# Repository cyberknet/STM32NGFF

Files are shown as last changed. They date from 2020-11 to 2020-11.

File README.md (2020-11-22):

# STM32NGFF
# About
STM32 breakout board using NGFF card edge connector

For licensing information please see our LICENSE file

Created by the members of 33C (fka reindeer pig baboon with mouse accessory)

## Schematic
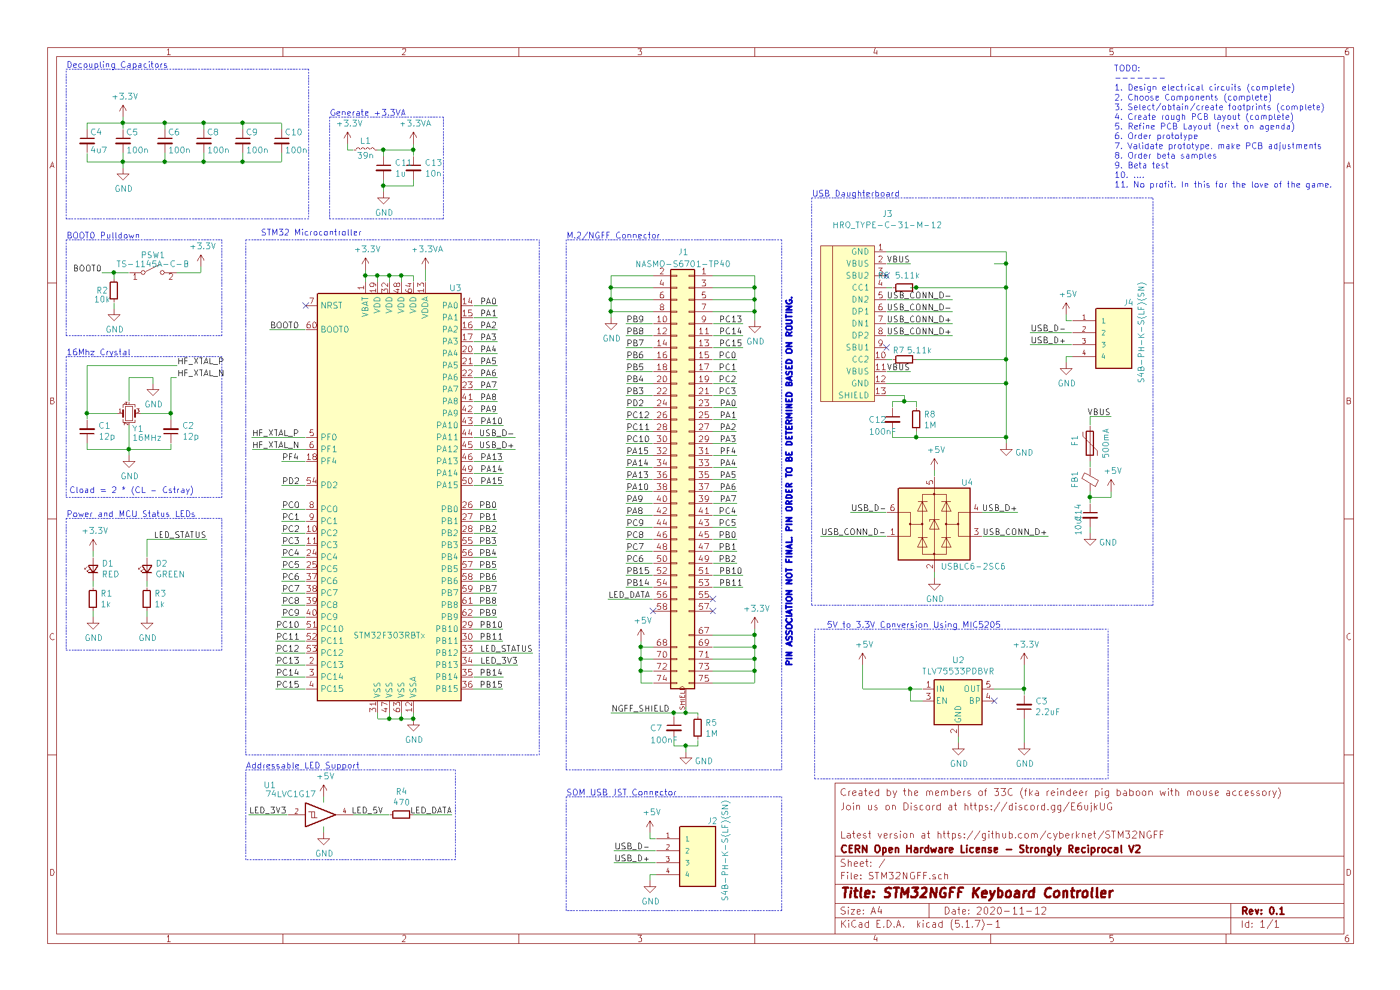
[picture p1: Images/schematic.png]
Keyboard Schematic


## PCB
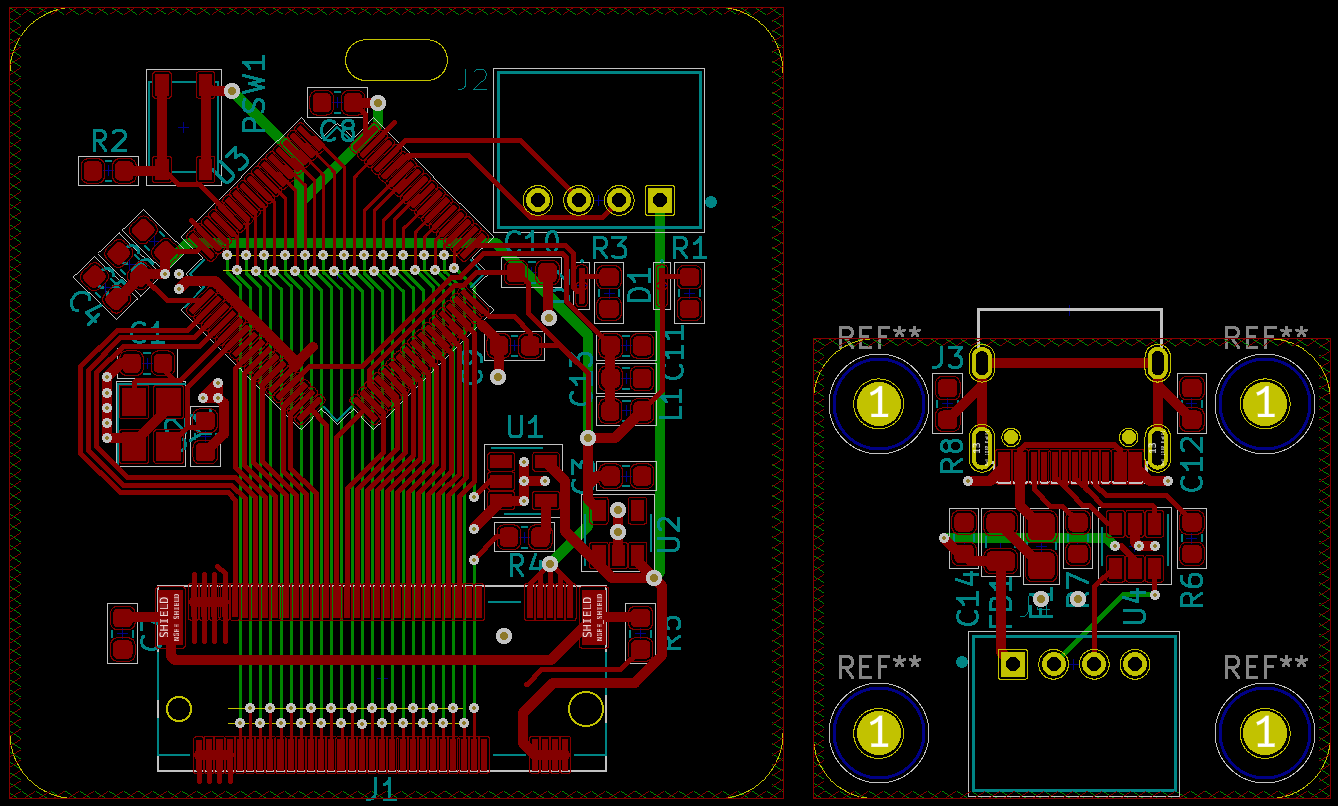
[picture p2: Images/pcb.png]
PCB


## PCB 3D View
Front:
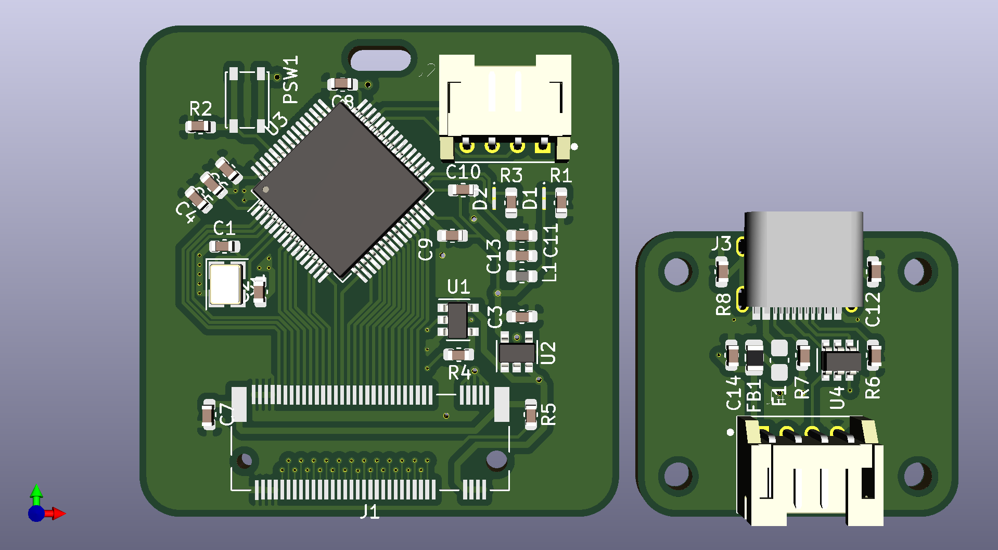
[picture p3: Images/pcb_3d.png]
PCB 3D Front View

Back:
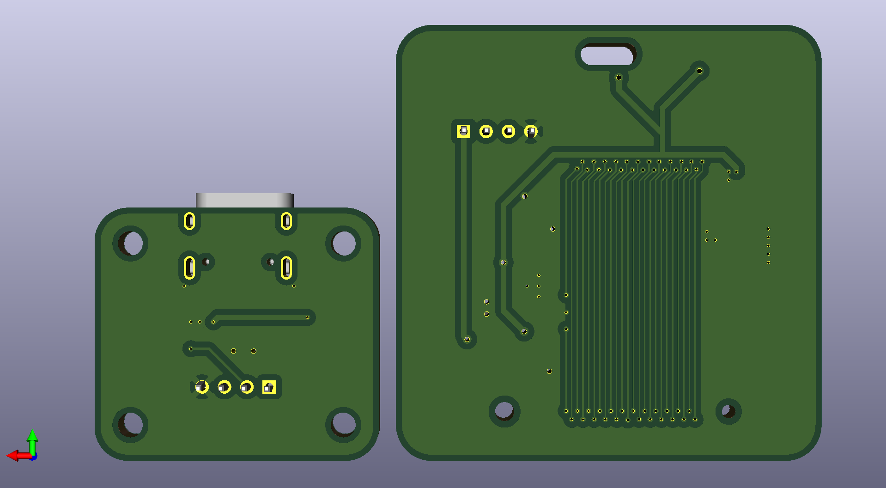
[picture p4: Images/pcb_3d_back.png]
PCB 3D Back View

Traces
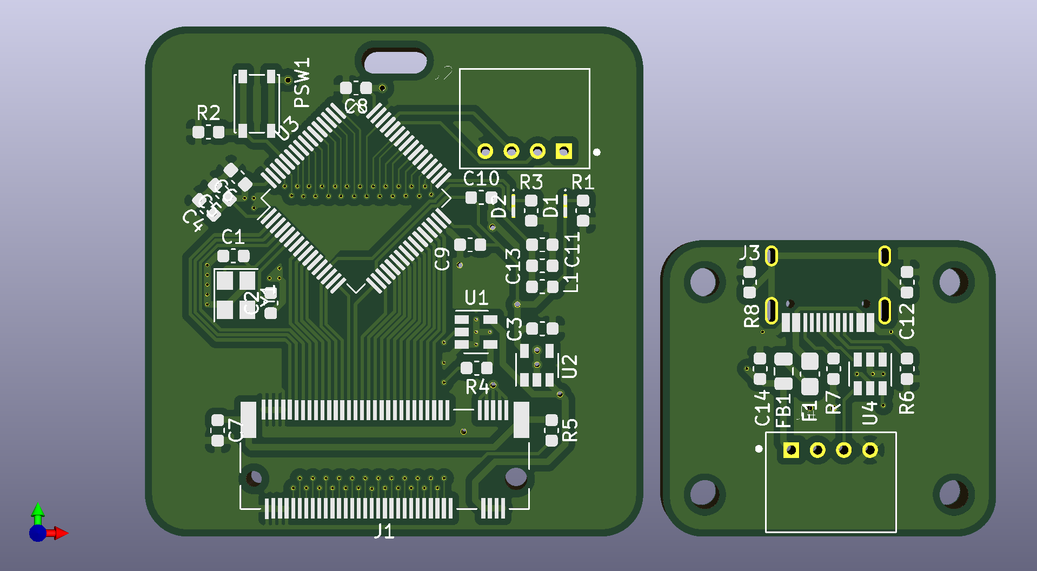
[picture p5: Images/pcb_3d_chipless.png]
PCB 3D Front Trace View


# Contact
Join us on Discord at https://discord.gg/E6ujkUG

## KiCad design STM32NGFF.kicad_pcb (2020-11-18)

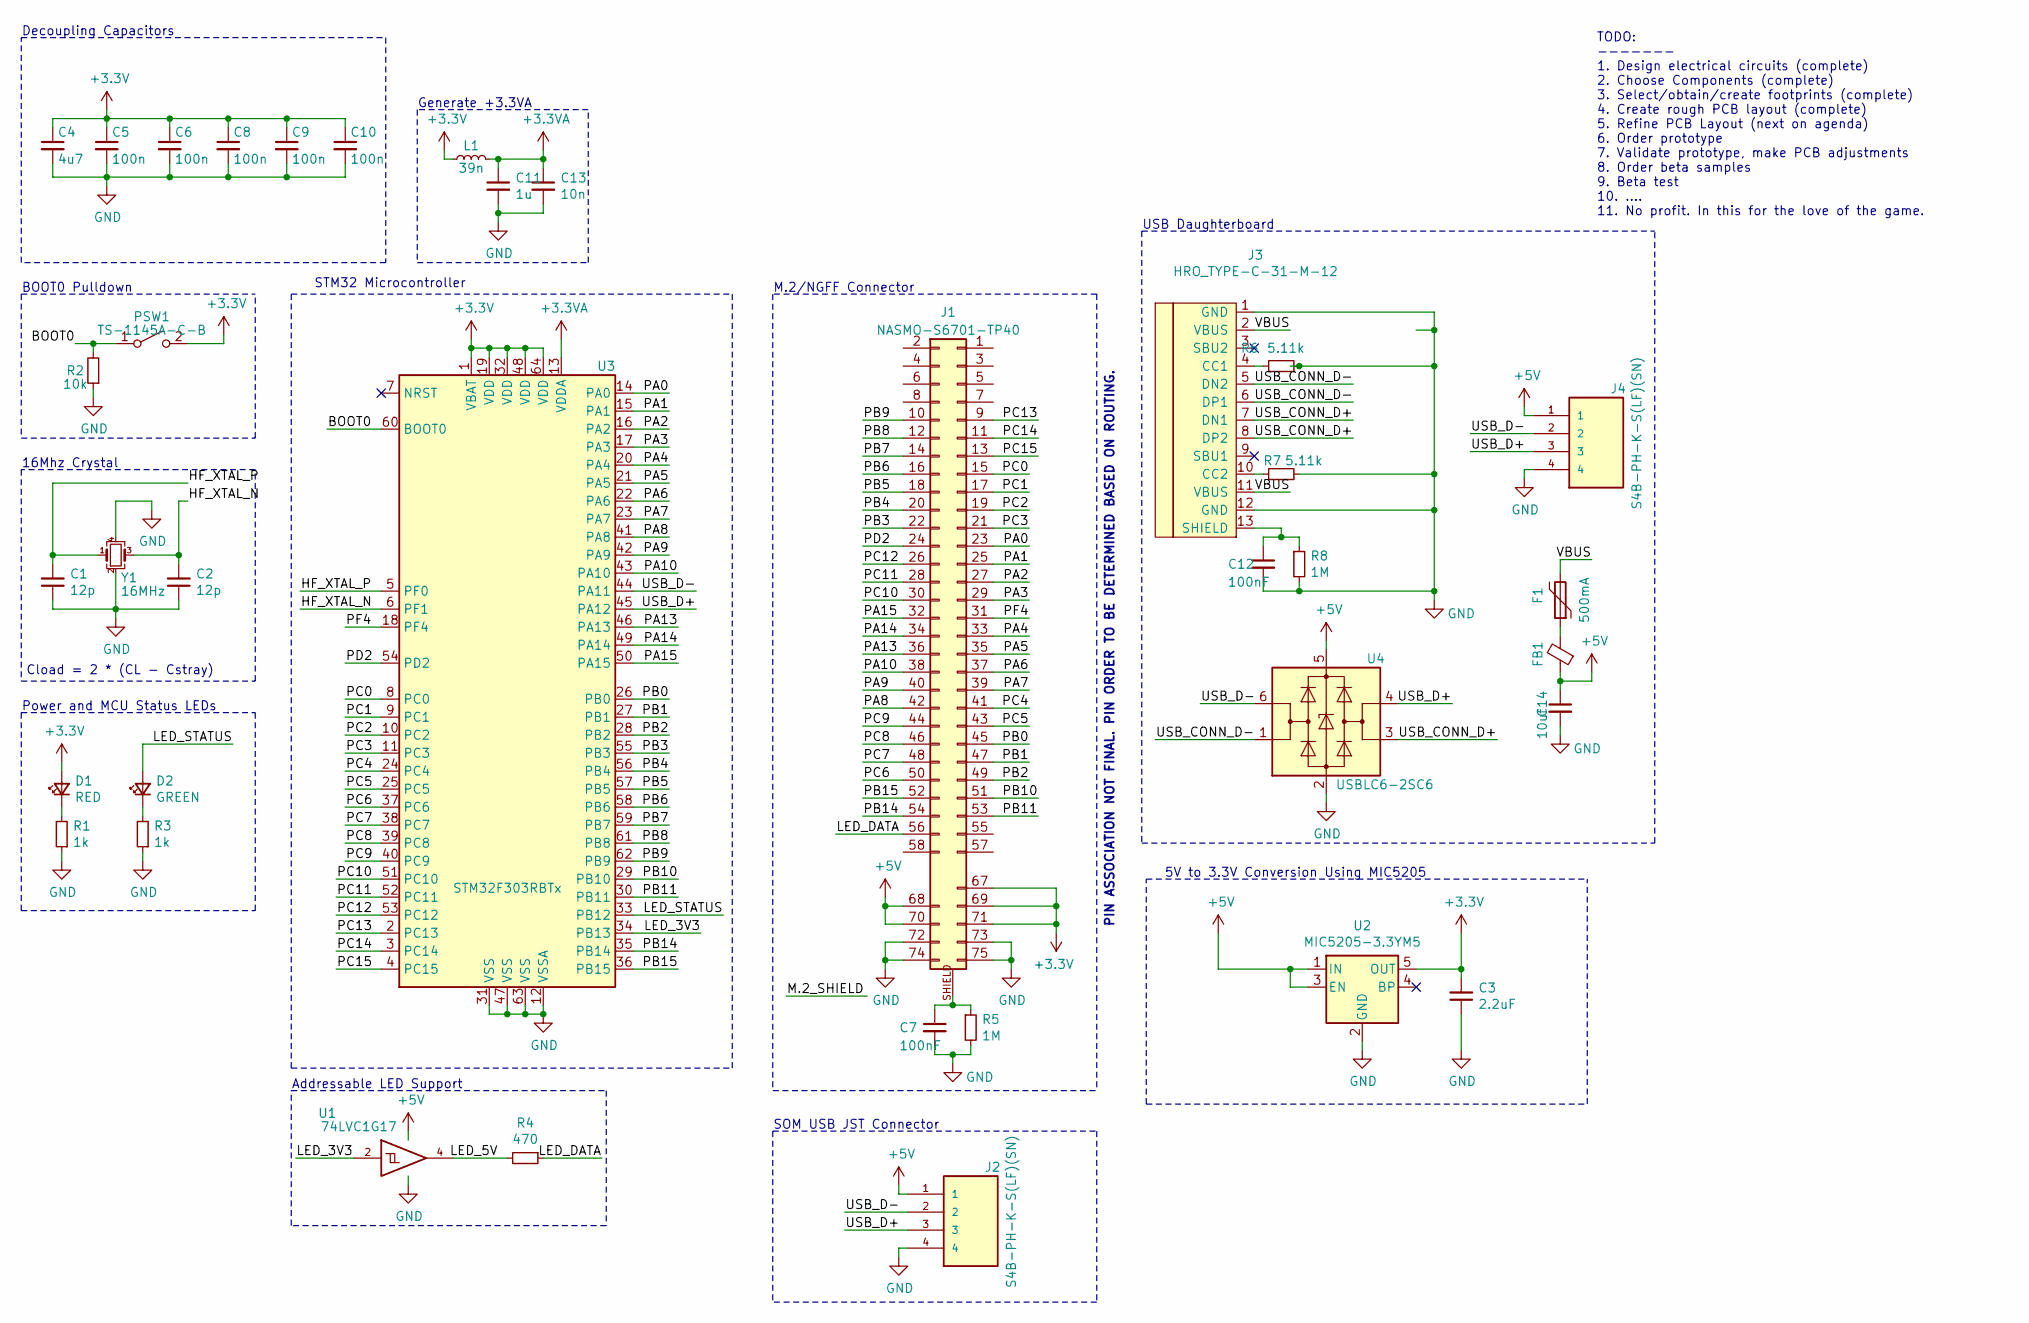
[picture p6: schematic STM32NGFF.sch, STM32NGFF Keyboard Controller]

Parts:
C1, C2: 12p; C_0603_1608Metric
C3: 2.2uF; C_0603_1608Metric
C4: 4u7; C_0603_1608Metric
C5, C6, C8, C9, C10: 100n; C_0603_1608Metric
C7, C12: 100nF; C_0603_1608Metric
C11: 1u; C_0603_1608Metric
C13: 10n; C_0603_1608Metric
C14: 10uf; C_0603_1608Metric
D1: RED; LED_0201_0603Metric_Castellated
D2: GREEN; LED_0201_0603Metric_Castellated
F1: 500mA; Fuse_0805_2012Metric_Castellated
FB1: Fuse_0805_2012Metric
J1: NASMO-S6701-TP40
J2, J4: S4B-PH-K-S(LF)(SN); S4B-PH-K-S_LF_SN
J3: HRO_TYPE-C-31-M-12; HRO-TYPE-C-31-M-12-Assembly
L1: 39n; L_0603_1608Metric
PSW1: TS-1145A-C-B; SW_SPST_PTS810
R1, R3: 1k; C_0603_1608Metric
R2: 10k; C_0603_1608Metric
R4: 470; C_0603_1608Metric
R5, R8: 1M; C_0603_1608Metric
R6, R7: 5.11k; C_0603_1608Metric
U1: 74LVC1G17; SOT-23-5
U2: MIC5205-3.3YM5; SOT-23-5
U3: STM32F303RBTx; LQFP-64_10x10mm_P0.5mm
U4: USBLC6-2SC6; SOT-23-6
Y1: 16MHz; Crystal_SMD_3225-4Pin_3.2x2.5mm

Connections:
+3.3VA: C11.1, C13.1, L1.2, U3.13 (VDDA)
+3V3: C3.2, C4.1, C5.1, C6.1, C8.1, C9.1, C10.1, D1.2 (A), J1.67, J1.69, J1.71, L1.1, PSW1.2 (B), U2.5 (OUT), U3.1 (VBAT), U3.19 (VDD), U3.32 (VDD), U3.48 (VDD), U3.64 (VDD)
+5V: C14.1, FB1.1, J1.68, J1.70, J2.1, J4.1, U1.5 (VCC), U2.1 (IN), U2.3 (EN), U4.5 (VBUS)
/BOOT0: PSW1.1 (A), R2.2, U3.60 (BOOT0)
/HF_XTAL_N: C2.2, U3.6 (PF1), Y1.3
/HF_XTAL_P: C1.2, U3.5 (PF0), Y1.1
/LED_3V3: U1.2, U3.34 (PB13)
/LED_5V: R4.2, U1.4
/LED_DATA: J1.56, R4.1
/LED_STATUS: D2.2 (A), U3.33 (PB12)
/PA0: J1.23, U3.14 (PA0)
/PA1: J1.25, U3.15 (PA1)
/PA2: J1.27, U3.16 (PA2)
/PA3: J1.29, U3.17 (PA3)
/PA4: J1.33, U3.20 (PA4)
/PA5: J1.35, U3.21 (PA5)
/PA6: J1.37, U3.22 (PA6)
/PA7: J1.39, U3.23 (PA7)
/PA8: J1.42, U3.41 (PA8)
/PA9: J1.40, U3.42 (PA9)
/PA10: J1.38, U3.43 (PA10)
/PA13: J1.36, U3.46 (PA13)
/PA14: J1.34, U3.49 (PA14)
/PA15: J1.32, U3.50 (PA15)
/PB0: J1.45, U3.26 (PB0)
/PB1: J1.47, U3.27 (PB1)
/PB2: J1.49, U3.28 (PB2)
/PB3: J1.22, U3.55 (PB3)
/PB4: J1.20, U3.56 (PB4)
/PB5: J1.18, U3.57 (PB5)
/PB6: J1.16, U3.58 (PB6)
/PB7: J1.14, U3.59 (PB7)
/PB8: J1.12, U3.61 (PB8)
/PB9: J1.10, U3.62 (PB9)
/PB10: J1.51, U3.29 (PB10)
/PB11: J1.53, U3.30 (PB11)
/PB14: J1.54, U3.35 (PB14)
/PB15: J1.52, U3.36 (PB15)
/PC0: J1.15, U3.8 (PC0)
/PC1: J1.17, U3.9 (PC1)
/PC2: J1.19, U3.10 (PC2)
/PC3: J1.21, U3.11 (PC3)
/PC4: J1.41, U3.24 (PC4)
/PC5: J1.43, U3.25 (PC5)
/PC6: J1.50, U3.37 (PC6)
/PC7: J1.48, U3.38 (PC7)
/PC8: J1.46, U3.39 (PC8)
/PC9: J1.44, U3.40 (PC9)
/PC10: J1.30, U3.51 (PC10)
/PC11: J1.28, U3.52 (PC11)
/PC12: J1.26, U3.53 (PC12)
/PC13: J1.9, U3.2 (PC13)
/PC14: J1.11, U3.3 (PC14)
/PC15: J1.13, U3.4 (PC15)
/PD2: J1.24, U3.54 (PD2)
/PF4: J1.31, U3.18 (PF4)
/USB_CONN_D+: J3.7 (DN1), J3.8 (DP2), U4.3 (I/O2)
/USB_CONN_D-: J3.5 (DN2), J3.6 (DP1), U4.1 (I/O1)
/USB_D+: J2.3, J4.3, U3.45 (PA12), U4.4 (I/O2)
/USB_D-: J2.2, J4.2, U3.44 (PA11), U4.6 (I/O1)
/VBUS: F1.2, J3.2 (VBUS), J3.11 (VBUS)
GND: C1.1, C2.1, C3.1, C4.2, C5.2, C6.2, C7.2, C8.2, C9.2, C10.2, C11.2, C12.2, C13.2, C14.2, J1.72, J1.73, J1.74, J1.75, J2.4, J3.1 (GND), J3.12 (GND), J4.4, R1.1, R2.1, R3.1, R5.2, R6.2, R7.2, R8.2, U1.3 (GND), U2.2 (GND), U3.12 (VSSA), U3.31 (VSS), U3.47 (VSS), U3.63 (VSS), U4.2 (GND), Y1.2, Y1.4
unnamed: C7.1, J1.SHIELD, R5.1
unnamed: C12.1, J3.13 (SHIELD), R8.1
unnamed: D1.1 (K), R1.2
unnamed: D2.1 (K), R3.2
unnamed: F1.1, FB1.2
unnamed: J3.4 (CC1), R6.1
unnamed: J3.10 (CC2), R7.1

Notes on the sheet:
Cload = 2 * (CL - Cstray)
STM32 Microcontroller
Power and MCU Status LEDs
USB Daughterboard
M.2/NGFF Connector
Decoupling Capacitors
16Mhz Crystal
Generate +3.3VA
BOOT0 Pulldown
TODO: ------- 1. Design electrical circuits (complete) 2. Choose Components (complete) 3. Select/obtain/create footprints (complete) 4. Create rough PCB layout (complete) 5. Refine PCB Layout (next on agenda) 6. Order prototype 7. Validate prototype, make PCB adjustments 8. Order beta samples 9. Be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
5V to 3.3V Conversion Using MIC5205
PIN ASSOCIATION NOT FINAL. PIN ORDER TO BE DETERMINED BASED ON ROUTING.
Addressable LED Support
SOM USB JST Connector

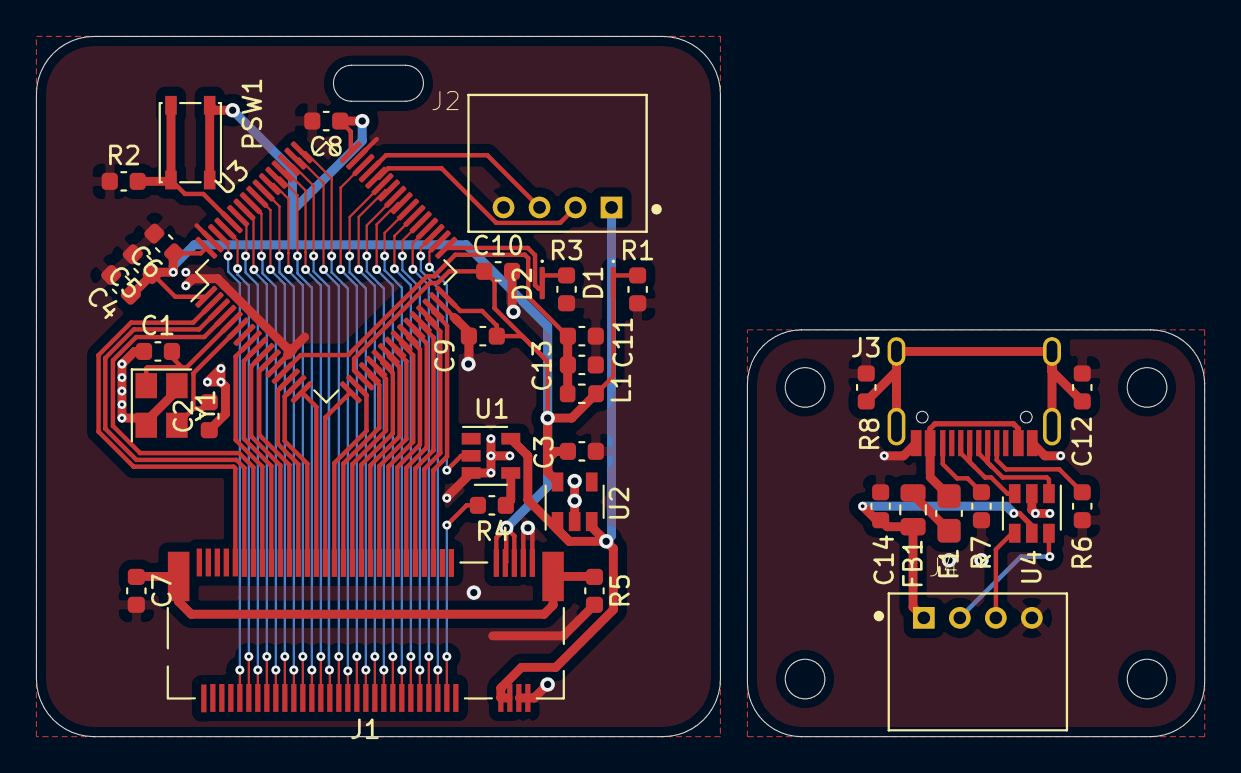
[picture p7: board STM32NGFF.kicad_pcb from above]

Board: 2 copper layers, 64.9 x 38.9 mm, 37 parts (0 on the bottom side), 69 nets.

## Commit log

2020-11-13 Added initial schematic
    [STM32NGFF.kicad_pcb, STM32NGFF.sch]
2020-11-13 added github repo to schematic and PCB
    [STM32NGFF.kicad_pcb, STM32NGFF.sch]
2020-11-13 Added LM117 implementation of 5V to 3.3V conversion
2020-11-13 Updated to built-in USB symbol and organized schematic
    [STM32NGFF.sch]
2020-11-13 Removed blank PCB and updated schematic with Discord info
    [STM32NGFF.kicad_pcb, STM32NGFF.sch]
2020-11-13 Updated 3.3V generation to MIC5205
    [STM32NGFF.sch]
2020-11-13 Finalized schematic and started PCB
    [STM32NGFF.kicad_pcb]
2020-11-13 Updated schematic in VC, ready for initial PCB
2020-11-13 Added initial PCB, and updated all global labels to net labels
    [STM32NGFF.kicad_pcb, STM32NGFF.sch]
2020-11-13 Updated page titles
    [STM32NGFF.kicad_pcb, STM32NGFF.sch]
2020-11-14 Add Correct M.2 Connector, and switch MCU to STM32F303RBTx
    [STM32NGFF.sch]
2020-11-18 Routed and shaped PCB
    [STM32NGFF.kicad_pcb, STM32NGFF.sch]
2020-11-18 Updated TODO list in schematic
    [STM32NGFF.sch]
2020-11-18 Updated images
    [STM32NGFF.kicad_pcb]
2020-11-22 Updated 3.3V Generator and NGFF footprint
    [STM32NGFF.sch]
2020-11-22 Updated NGFF pinout for 3.3V, 5V, and GND
    [STM32NGFF.sch]
2020-11-22 Added PCB back view, and chipless view of front
2020-11-22 Updated README.md to include new board views

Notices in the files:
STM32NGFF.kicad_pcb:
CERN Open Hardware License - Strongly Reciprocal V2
